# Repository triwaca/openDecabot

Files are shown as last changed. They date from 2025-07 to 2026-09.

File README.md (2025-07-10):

# openDecabot
The easiest 3D printed robot you can assemble and program using Wemos D1 Mini Shields and Arduino IDE, powered by ESP8266. 

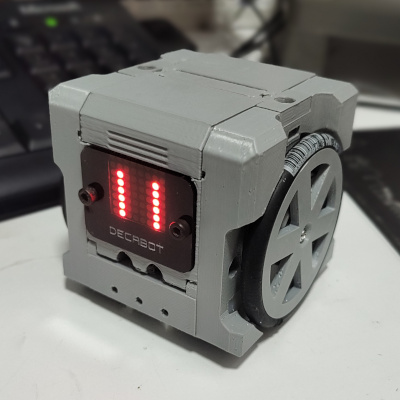
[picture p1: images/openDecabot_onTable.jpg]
Decabot robot on a Table

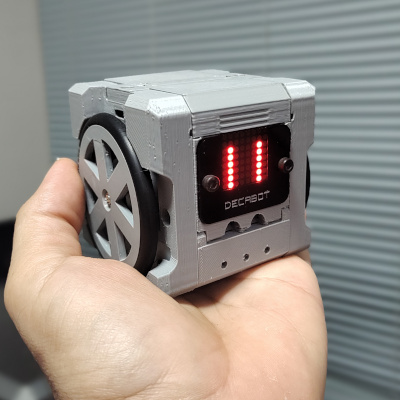
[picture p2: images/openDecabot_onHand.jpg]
A hand holding a Decabot robot


## Hardware
### ESP8266 microcontroler
Open Decabot® uses the ESP8266 controler, in the Wemos Mini form factor, wich allows to use small shields to expand its capacities. In the simplest version, this robot uses a LED matrix shield and a custom connection shield, besides the Wemos D1 mini. The custom shield can be build with a PCB perfboard, a few pin header connections, and some soldering skills. 

By using the Espressif ESP8266 platform, the open Decabot® is nativelly equiped with Wi-Fi capabilities, allowing great IoT experiences, such as remote control and telemetry. 

More information about Wemos platform and a list of main shields available can be found on www.wemos.cc .

### Servo Motors
The open Decabot® robot uses two 360 servo motors to drive its wheels. It's the simplest solution for small robots, since the servo motors didin't require H bridge circuits (they already have those inside!) and can be connected directly to the ESP8266 pins. 

### 3D printed body
You can assemble your Open Decabot® using 3D printed parts. The basic chassis uses only 8 3D printed pieces, and can be assembled using a few screws. The 3D files can be found on **3dPrint** folder. 

### Simple AA batteries for power
Under the open Decabot® you can find a 4 x AA battery support, who can supply up to 6V directly to ESP board. This option simplifies the hardware, since the Wemos Mini board can hold the maxminum 6 volts, lowering the tension to 3 volts. Users can hack the project to use LiIon batteries, combined with the Wemos LiPo Battery Shield (https://www.wemos.cc/en/latest/d1_mini_shield/battery.html) for charging and step up the voltage to 5 volts. 

### Easy access to USB ports
There are two ports on the upper part of the robot who can be used to access the USB port (for firmware/Arduino sketch update), and other wiring and shield needs. 

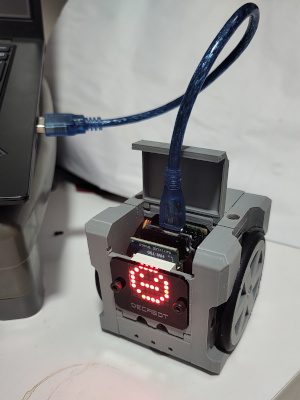
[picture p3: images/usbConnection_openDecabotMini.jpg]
Decabot robot conneceted using USB cable to a computer


### Bill of Materials - BOM
- 1 x Wemos D1 Mini ESP8266 controller
- 2 x Servo 5V 360
- 1 x Wemos LED Matrix Shield
- 1 x custom PCB board (check wiki how to build one) or 1 x Decabot Mini Shield PCB (see **/decabotMiniShield** folder)
- 1 x battery support for 4 x AA
- 1 x acrylic frontface + 2 hallen 3mm screws (optional)
- 7 x screws 3mm, 12mm long
- 2 x rubber o-ring for wheels, size 2" or 50mm (ref: DN50)
- 4 x AA batteries

### Decabot Mini Shield

#### Homemade PDB
Wemos platform does not have a simple shield board to connect servos, so you need a homemade board to use. It's goal is just to simplify the connection between the controller and the motors. A homemade PDB board can be assembled just to connect the main components to the Wemos board: Battery to 5V pin, and servos to D0 and D6 pins, as shown below:

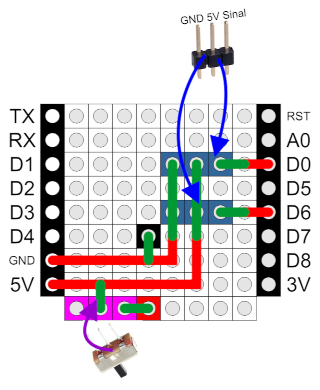
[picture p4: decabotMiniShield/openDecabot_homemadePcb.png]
Homemade Decabot Mini PCB


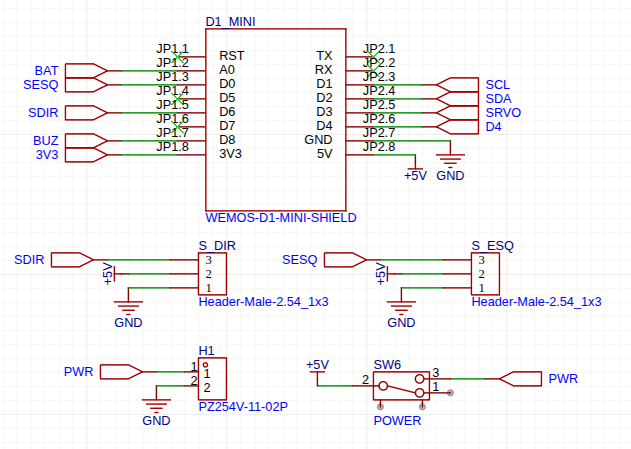
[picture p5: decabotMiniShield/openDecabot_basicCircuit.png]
Homemade PCB circuit


#### Buy the Decabot Shield

Help funding this project by buying our dedicated shield. It is the easiest way to enjoy all the possibilities of your Open Decabot Robot!

- Easy access to Servo connections
- On-off switch
- Included buzzer for sounds
- Easy connection for extra sensors, such as line-folowing sensors
- Dedicated connection to Gyroscope/Accelerometer, for mapping projects
- Dedicated connection to I2C modules, such as OLED displays, distance sensors, RGB sensors and RFID/NFC sensors

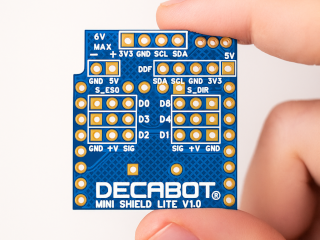
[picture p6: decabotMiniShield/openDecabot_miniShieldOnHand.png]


More information about commercial partnership on WIKI soon.

## Arduino Codes

The Arduino sketches can be found on **/ArduinoSketch** folder. You can simply copy this folder inside your Arduino folder on your computer, and open the `.ino` files. 

Remember that Decabot platform is based on `ESP8266` chip, in Wemos D1 Mini form factor. Your Arduino IDE must be proper set to manage ESP8266 family. To se if it is ready, go to `Tools` menu, then `Boards`, and look for `ESP8266 boards`. You must find `Wemos D1 Mini` there. If not, google for _installing ESP8266 on Arduino IDE_.

Some sketches uses libraries who must be installed before. See instructions on each sketch how to proceed. 

## 3D project source
The 3D source project was all designed on Tinkercad (yes!), and can be forked using the link below:
https://www.tinkercad.com/things/dYy4XWihfYu-opendecabot-mini-v10

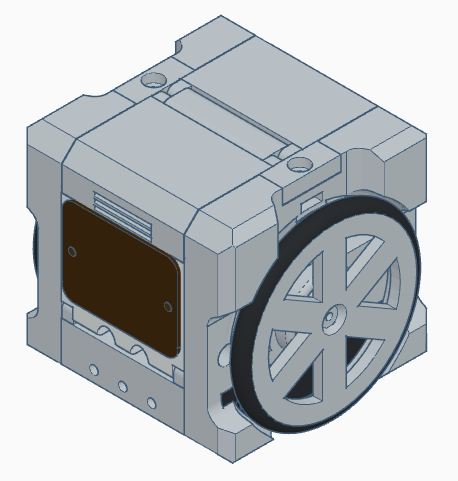
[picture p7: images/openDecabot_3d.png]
Decabot robot on Tinkercad


## Decabot® Trade Mark
Besides this project is open source, the Decabot® name is a registered trademark from Decano Kits Company, and should not be used without proper consent. 

## Open Source Licenses

Open Decabot® project is licensed under CC BY-NC-SA 4.0. You are free to:

- Share — copy and redistribute the material in any medium or format
- Adapt — remix, transform, and build upon the material

Under the following terms:

- Attribution — You must give appropriate credit , provide a link to the license, and indicate if changes were made . You may do so in any reasonable manner, but not in any way that suggests the licensor endorses you or your use.
- NonCommercial — You may not use the material for commercial purposes .
- ShareAlike — If you remix, transform, or build upon the material, you must distribute your contributions under the same license as the original.

https://creativecommons.org/licenses/by-nc-sa/4.0/

Creative Commons License By NC SA

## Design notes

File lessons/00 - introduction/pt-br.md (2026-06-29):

# Introdução: Plataforma Wemos D1 Mini

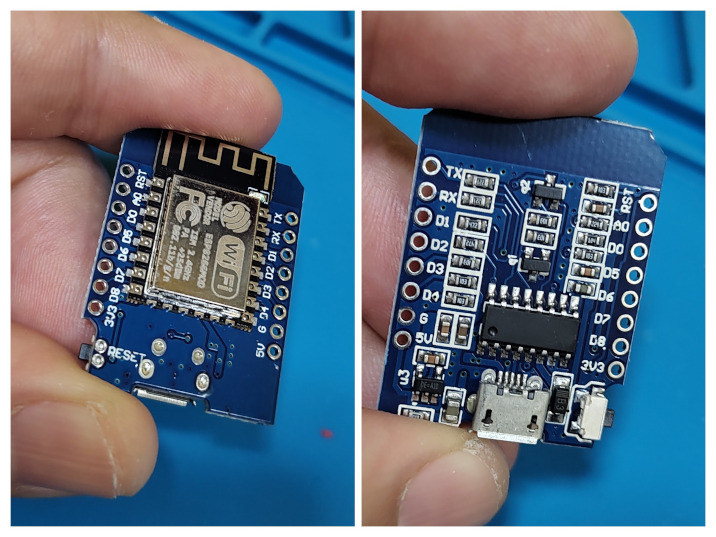
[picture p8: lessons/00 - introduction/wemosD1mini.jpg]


A plataforma **Wemos D1 Mini** é uma das placas de desenvolvimento mais populares e eficientes do ecossistema de Internet das Coisas (IoT) e sistemas embarcados. Baseada no módulo Wi-Fi **ESP8266EX**, ela combina um tamanho extremamente reduzido (form factor *mini*) com um poder de processamento e conectividade robustos, tornando-se uma ferramenta indispensável tanto para o ensino acadêmico quanto para o desenvolvimento de protótipos avançados de robótica open-source e automação.

## 1. Características Técnicas

O Wemos D1 Mini supera as placas tradicionais de 8 bits (como o Arduino Uno) em quase todas as métricas de desempenho, operando com uma arquitetura de 32 bits e conectividade sem fio nativa.

* **Microcontrolador:** ESP-8266EX (Processador RISC de 32 bits Tensilica L106)
* **Tensão de Operação:** 3.3V (Atenção: as entradas não são tolerantes a 5V de forma direta)
* **Tensão de Entrada (USB/Pino 5V):** 4.75V a 10V (possui regulador interno para 3.3V)
* **Velocidade de Clock:** 80 MHz (podendo ser configurado até 160 MHz)
* **Memória Flash:** 4 Megabytes (32 Megabits) para armazenamento de código e sistema de arquivos (SPIFFS/LittleFS)
* **SRAM:** Cerca de 50 KB disponíveis para o usuário
* **Conectividade:** Wi-Fi integrado 802.11 b/g/n com antena embutida na PCB
* **Pinos de Entrada/Saída Digital (GPIO):** 11 pinos, todos com suporte a Interrupção, PWM, I2C e One-Wire (exceto o pino D0)
* **Pino de Entrada Analógica (ADC):** 1 entrada (A0) com resolução de 10 bits (tensão máxima de entrada de 3.2V devido ao divisor resistivo interno da placa; o chip puramente aceita até 1V)
* **Interface USB:** Conversor USB-Serial integrado (geralmente CH340 ou CP2104) com conector Micro-USB

---

## 2. Pinagem (Pinout) e Funções Especiais

Ao montar sua Wemos D1 mini lembre-se de escolher corretamente o pino duplo, posicionando para cima os pinos fêmeas, e na parte de baixo os pinos machos, conforme imagem:

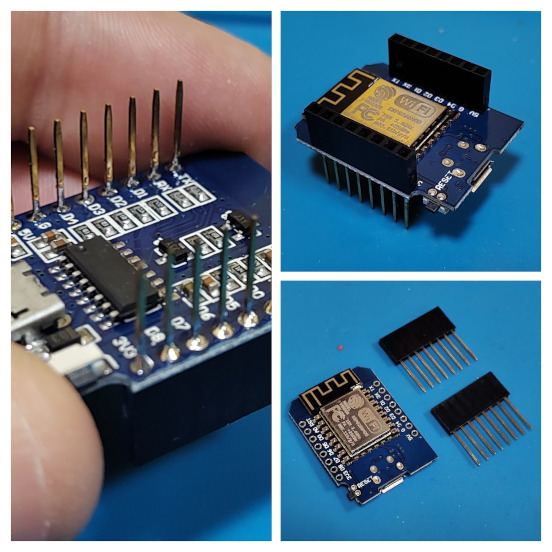
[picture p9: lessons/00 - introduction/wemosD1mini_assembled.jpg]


Compreender a pinagem do Wemos D1 Mini é fundamental, pois os rótulos gravados na placa (D0 a D8) não correspondem diretamente aos números das portas lógicas (GPIO) internos usados na programação.
| Rótulo na Placa | GPIO Interno | Funções Principais / Notas de Boot |
| :--- | :--- | :--- |
| **TX** | GPIO 1 | Transmissão Serial (U0TXD). Pisca no boot. |
| **RX** | GPIO 3 | Recepção Serial (U0RXD). Alto no boot. |
| **D0** | GPIO 16 | Wake do modo Deep Sleep. Sem suporte a PWM/Interrupção. |
| **D1** | GPIO 5 | **SCL** (I2C por hardware / padrão). |
| **D2** | GPIO 4 | **SDA** (I2C por hardware / padrão). |
| **D3** | GPIO 0 | Conectado a um resistor de Pull-up interno. **Deve estar em nível ALTO no boot** para entrar no modo de execução. |
| **D4** | GPIO 2 | Conectado ao **LED Azul Integrado** (lógica invertida: LOW liga, HIGH desliga). Emite dados de debug no boot. |
| **D5** | GPIO 14 | **CLK** (SPI por hardware). |
| **D6** | GPIO 12 | **MISO** (SPI por hardware). |
| **D7** | GPIO 13 | **MOSI** (SPI por hardware). |
| **D8** | GPIO 15 | **CS** (SPI por hardware). Conectado a um resistor de Pull-down interno. **Deve estar em nível BAIXO no boot**. |
| **A0** | ADC0 | Entrada Analógica (0V a 3.2V). |
| **RST** | RST | Pino de Reset da placa (Ativo em nível BAIXO). |
| **5V** | — | Saída de 5V (quando alimentado por USB) ou Entrada de Alimentação Externa. |
| **3V3** | — | Saída do regulador interno de 3.3V (máximo ~500mA). |
| **GND** | — | Referência de aterramento (Ground). |

---

## 3. Vantagens do Uso de Shields Wemos D1 Mini

Uma das maiores forças desta plataforma é o seu ecossistema de **Shields** (placas de expansão modulares). Elas eliminam a necessidade de fiação complexa e trazem vantagens significativas:

* **Prototipagem Rápida e Limpa:** As shields possuem exatamente o mesmo tamanho e disposição de pinos da placa principal. Elas podem ser empilhadas diretamente usando barras de pinos macho-fêmea, eliminando emaranhados de cabos jumpers e o uso excessivo de protoboards.
* **Redução de Pontos de Falha:** Mau contato em fios jumpers é um dos problemas mais comuns em projetos laboratoriais e robóticos móveis. A conexão soldada das shields garante integridade mecânica e elétrica.
* **Compactação do Projeto:** Permite criar dispositivos IoT completos (com sensores, displays e atuadores) que cabem dentro de pequenas caixas ou estruturas robóticas compactas.
* **Variedade de Recursos Prontos:** Existem dezenas de shields oficiais e compatíveis no mercado, tais como:
  * *Relay Shield:* Para controle de cargas de alta tensão (lâmpadas, motores).
  * *OLED Shield:* Telas compactas de 64x48 ou 128x64 pixels para interface visual.
  * *DHT11/DHT22 Shield:* Sensores de temperatura e umidade prontos para leitura.
  * *Battery Shield:* Circuito integrado para carregar e gerenciar baterias de Lítio (LiPo) de 3.7V, ideal para robôs móveis.
  * *MicroSD Card Shield:* Para datalogging (registro de dados locais).

Conheça todas as shield disponíveis acessando o site wemos em www.wemos.cc .

---

## 4. Tutorial: Configurando a Arduino IDE para o Wemos D1 Mini

Para programar o Wemos D1 Mini usando a linguagem baseada em C/C++ do Arduino, siga os passos abaixo:

### Passo 1: Adicionar a URL do ESP8266 nas Preferências

1. Abra a **Arduino IDE**.

2. No menu superior, clique em **Arquivo** > **Preferências** (no macOS: *Arduino IDE* > *Settings*).

3. Localize o campo chamado **URLs Adicionais para Gerenciadores de Placas**.

4. Cole a seguinte URL exatamente como descrita:
   
   ```text
   http://arduino.esp8266.com/stable/package_esp8266com_index.json
   ```

5. Clique em **OK** para salvar.
   
   ### Passo 2: Instalar o Pacote de Placas ESP8266

6. No menu lateral esquerdo da Arduino IDE, clique no ícone do **Gerenciador de Placas** (ou vá em *Ferramentas* > *Placa* > *Gerenciador de Placas...*).

7. Na barra de pesquisa que aparecer, digite **esp8266**.

8. Localize o pacote chamado **esp8266** criado pela *ESP8266 Community*.

9. Clique no botão **Instalar** e aguarde o término do download e configuração (isso pode levar alguns minutos).
   
   ### Passo 3: Selecionar a Placa Correta

10. Vá no menu superior em **Ferramentas** > **Placa** > **ESP8266 Boards**.

11. Procure e selecione a opção **LOLIN(WEMOS) D1 R2 & mini**.
    
    ### Passo 4: Instalar os Drivers e Conectar a Placa

12. Conecte o Wemos D1 Mini ao computador através de um cabo Micro-USB (certifique-se de que o cabo suporta transferência de dados, e não apenas energia).

13. Se a sua placa utilizar o chip de comunicação **CH340** e o seu sistema operacional não o reconhecer automaticamente, faça o download e a instalação do driver *CH340 Serials Driver* (disponível para Windows, Mac e Linux).

14. Na Arduino IDE, vá em **Ferramentas** > **Porta** e selecione a porta correspondente (ex: `COM3`, `COM4` no Windows, ou `/dev/tty.usbserial` no Unix).
    
    ### Passo 5: Teste Prático (Blink)
    
    Para validar se tudo está funcionando, carregue o código de teste padrão que pisca o LED embutido utilizando a constante correta da placa:
    
    ```cpp
    void setup() {
        // Configura o pino do LED interno como saída
        pinMode(LED_BUILTIN, OUTPUT); 
    }
    void loop() {
        // Liga o LED (Lógica invertida: LOW ativa o LED interno no Wemos)
        digitalWrite(LED_BUILTIN, LOW); 
        delay(5000); // Mantém ligado por 5 segundos
    
        // Desliga o LED
        digitalWrite(LED_BUILTIN, HIGH); 
    delay(1000); // Mantém desligado por 1 segundo
    }
    ```

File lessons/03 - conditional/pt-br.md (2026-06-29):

# Condicionais e Comunicação Serial no Wemos D1 Mini

Este repositório contém um guia prático projetado para introduzir estudantes de robótica, automação e sistemas embarcados aos conceitos de **Comunicação Serial** e **Estruturas Condicionais (`if`, `else if`, `else`)** utilizando a placa **Wemos D1 Mini (ESP8266)** e a plataforma Arduino.

## 📋 Pré-requisitos

Antes de iniciar, certifique-se de ter os seguintes itens configurados:

### Hardware

* 1x Placa Wemos D1 Mini (ou qualquer módulo baseado no ESP8266)

* 1x Cabo de dados Micro-USB
  
  ### Software

* **Arduino IDE** (versão 1.8.x ou 2.x)

* Placas da família **ESP8266 instaladas** na IDE (Gerenciador de Placas)

* Drivers do chip de comunicação USB instalados (geralmente CH340)

---

## ⚡ Passo 1: O que é a Comunicação Serial?

A **Comunicação Serial** funciona como uma ponte de texto entre o microcontrolador e o seu computador. Em projetos de desenvolvimento, ela é a nossa principal ferramenta de diagnóstico (debug), permitindo-nos "espiar" o que está acontecendo dentro do chip.
No ecossistema Arduino, iniciamos essa comunicação usando o comando:

```cpp
Serial.begin(velocidade);
```

> [!IMPORTANT]
> **Por que usar 115200 bps no Wemos D1 Mini?**
> Diferente do Arduino Uno clássico (que costuma usar 9600), os microcontroladores da família ESP8266 inicializam o bootloader a uma taxa de **115200 bps**. Configurar o sistema nessa velocidade evita que você veja caracteres corrompidos ou ilegíveis (lixo de memória) na tela no momento em que a placa é resetada ou ligada.

### Comandos de Escrita Serial:

* `Serial.print("Texto");` -> Envia a informação e mantém o cursor na **mesma linha**.
* `Serial.println("Texto");` -> Envia a informação e **pula para a próxima linha** (adiciona uma quebra de linha `\n` ao final).

---

## 🔍 Passo 2: Como Visualizar os Dados na Arduino IDE

Para conseguir ler o que o Wemos D1 Mini está enviando, siga o procedimento abaixo:

1. Conecte o Wemos D1 Mini ao computador pelo cabo USB.
2. Na Arduino IDE, vá em **Ferramentas > Placa** e selecione `LOLIN(WEMOS) D1 R2 & mini` (ou `Generic ESP8266 Module`).
3. Vá em **Ferramentas > Porta** e selecione a porta COM associada à sua placa.
4. Clique no ícone do **Monitor Serial** (uma lupa no canto superior direito da IDE) ou pressione o atalho `Ctrl + Shift + M`.
5. **Ajuste essencial:** Na janela do Monitor Serial que se abriu, mude a velocidade no menu suspenso para **115200 baud**. Se estiver em outra velocidade, você não conseguirá ler o texto correto.

---

## 🧠 Passo 3: Entendendo as Estruturas Condicionais

As condicionais permitem que o microcontrolador execute ações diferentes dependendo do estado das variáveis ou sensores.

* **`if` (Se):** Avalia se uma condição é verdadeira. Se for, executa o bloco de código interno.
* **`else if` (Senão se):** Fornece uma nova condição para ser testada caso as anteriores tenham sido falsas.
* **`else` (Senão):** É a zona de escape. Executa um código padrão caso **nenhuma** das condições anteriores tenha sido atendida.

---

## 💻 Passo 4: Código Prático (Simulação de um Sensor de Distância)

Neste exemplo realístico, simulamos a lógica interna de um pequeno robô móvel que precisa desviar de obstáculos. A variável `distanciaObstaculo` decresce a cada ciclo para forçar o código a passar por todas as ramificações lógicas.
Copie o código abaixo, cole na sua Arduino IDE e clique em **Carregar (Upload)**:

```cpp
/**
 * @file Tutorial_Condicionais.ino
 * @brief Aprendendo condicionais e comunicação serial com o Wemos D1 Mini.
 * @author Professor / Instrutor
 */
// Variável global para simular a leitura de distância em centímetros (cm)
int distanciaObstaculo = 35; 
void setup() {
  // Inicializa a comunicação serial a 115200 bits por segundo (bps)
  Serial.begin(115200);

  // Pequeno intervalo de segurança para inicialização estável da placa
  delay(1000); 

  Serial.println("");
  Serial.println("=========================================");
  Serial.println("   SISTEMA DE DECISÃO LOGICA DO ROBÔ     ");
  Serial.println("=========================================");
}
void loop() {
  // Exibe a distância simulada atual no monitor
  Serial.print("Sensor de Distância: ");
  Serial.print(distanciaObstaculo);
  Serial.println(" cm");
  // --- INÍCIO DA TOMADA DE DECISÃO ---

  // Condição 1: Perigo imediato
  if (distanciaObstaculo <= 10) {
    Serial.println(" Alerta: [PERIGO] - Parar imediatamente! Risco de colisão.");
  }

  // Condição 2: Zona de atenção (Uso do operador lógico '&&' para verificar o intervalo)
  else if (distanciaObstaculo > 10 && distanciaObstaculo <= 30) {
    Serial.println(" Alerta: [ATENÇÃO] - Reduzir velocidade. Obstáculo próximo.");
  }

  // Condição 3: Caminho livre (Qualquer valor acima de 30)
  else {
    Serial.println(" Status: [LIVRE] - Velocidade máxima permitida.");
  }
  Serial.println("-----------------------------------------");
  // --- SIMULAÇÃO DA MUDANÇA DE ESTADO ---
  // Subtrai 8 cm da distância a cada execução para simular a aproximação do robô
  distanciaObstaculo = distanciaObstaculo - 8;
  // Se a distância se tornar negativa, reiniciamos a simulação para fins didáticos
  if (distanciaObstaculo < 0) {
    distanciaObstaculo = 40; 
    Serial.println("\n>>> [RESET] Reiniciando simulação de trajetória... <<<\n");
  }
  // Tempo de espera de 3 segundos para que os alunos possam ler confortavelmente
  delay(3000); 
}
```

---

## 📈 Resultado Esperado no Monitor Serial

Ao abrir o Monitor Serial configurado corretamente em `115200 baud`, os alunos deverão observar a seguinte sequência cíclica de mensagens de texto na tela:

```text
=========================================
   SISTEMA DE DECISÃO LOGICA DO ROBÔ     
=========================================
Sensor de Distância: 35 cm
 Status: [LIVRE] - Velocidade máxima permitida.
-----------------------------------------
Sensor de Distância: 27 cm
 Alerta: [ATENÇÃO] - Reduzir velocidade. Obstáculo próximo.
-----------------------------------------
Sensor de Distância: 19 cm
 Alerta: [ATENÇÃO] - Reduzir velocidade. Obstáculo próximo.
-----------------------------------------
Sensor de Distância: 11 cm
 Alerta: [ATENÇÃO] - Reduzir velocidade. Obstáculo próximo.
-----------------------------------------
Sensor de Distância: 3 cm
 Alerta: [PERIGO] - Parar imediatamente! Risco de colisão.
-----------------------------------------
>>> [RESET] Reiniciando simulação de trajetória... <<<
Sensor de Distância: 40 cm
 Status: [LIVRE] - Velocidade máxima permitida.
```

---

## 🚀 Desafios para Fixação (Prática em Laboratório)

Para garantir o aprendizado e testar o raciocínio lógico dos estudantes, proponha as seguintes modificações no código:

1. **Alerta Intermediário Exato:** Peça aos alunos para adicionarem uma condição usando `else if` que identifique quando a distância for exatamente `15` cm e imprima uma instrução específica no terminal, por exemplo: `" Status: [INFO] - Manobrar para a direita."` (Lembre-os de usar o operador de igualdade `==`).
2. **Alteração do Passo de Atualização:** Peça para alterarem o decremento do sensor (atualmente em `- 8`) para um valor menor, como `- 3`, e incentive-os a analisar o impacto desse valor na frequência com que os alertas mudam de estado.
3. **Uso de Operadores Relacionais:** Peça para modificarem o código para que o status `[PERIGO]` passe a cobrir qualquer valor menor ou igual a `15` cm, ajustando os intervalos lógicos subsequentes de forma coerente.

---

## 🛠️ Resolução de Problemas Comuns

* **O Monitor Serial exibe caracteres estranhos (`⸮⸮⸮` ou interrogações):** A velocidade do monitor está diferente de `115200`. Altere a caixa de seleção no canto inferior direito para o valor correto.
* **Erro ao carregar o código (Failed to connect to ESP8266):** O cabo USB pode ser apenas de carregamento (sem linhas de dados), a porta COM errada foi selecionada ou os drivers do chip CH340 precisam ser reinstalados.

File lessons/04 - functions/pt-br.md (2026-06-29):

# Tutorial Prático: Criando e Utilizando Funções no Arduino

Bem-vindos a este guia pedagógico sobre estruturação de código. Quando nossos programas começam a crescer — seja controlando um semáforo complexo, lendo múltiplos sensores ou gerenciando a movimentação de um robô como o Decabot —, colocar todo o código dentro das funções `setup()` e `loop()` torna o projeto confuso, difícil de depurar e propenso a erros.
As **funções** são blocos de código independentes e reutilizáveis que realizam tarefas específicas. Elas nos ajudam a modularizar o sistema, evitar a repetição de código (princípio DRY - *Don't Repeat Yourself*) e tornar a leitura muito mais intuitiva.

---

## A Estrutura de uma Função

Toda função em C/C++ (linguagem base do Arduino) segue uma anatomia padrão:

```cpp
tipoDeRetorno nomeDaFuncao(tipoParametro1 parametro1, tipoParametro2 parametro2) {
    // Corpo da função (código que será executado)
    return valor; // Opcional (apenas se houver tipo de retorno)
}
```

Para entender como utilizá-las na prática, vamos dividi-las em 4 categorias baseadas na presença de **parâmetros de entrada** (dados que a função recebe) e **retornos** (dados que a função envia de volta).

## 1. Funções Sem Parâmetros e Sem Retorno

É o tipo mais simples de função. Ela serve apenas para agrupar um conjunto de instruções que você deseja executar repetidamente, sem a necessidade de enviar ou receber dados de fora.

* **Tipo de retorno:** Usamos a palavra-chave `void` (vazio), indicando que ela não devolve nada.

* **Parâmetros:** Os parênteses ficam vazios `()`.
  
  ### Exemplo Prático:
  
  Imagine que queremos criar um padrão de alerta visual piscando um LED de forma específica.
  
  ```cpp
  const int ledPin = D4; // LED embutido no Wemos D1 Mini
  
  void setup() {
      pinMode(ledPin, OUTPUT);
  }
  
  void loop() {
      // Chamamos a nossa função personalizada
      emitirAlertaSOS(); 
      
      delay(3000); // Aguarda 3 segundos antes de repetir o Alerta
  }
  
  // Definição da nossa função
  void emitirAlertaSOS() {
      // Três piscadas rápidas
      for(int i = 0; i < 3; i++) {
        digitalWrite(ledPin, LOW);  // Liga (Active-LOW no Wemos)
        delay(200);
        digitalWrite(ledPin, HIGH); // Desliga
        delay(200);
      }
  }
  ```

---

## 2. Funções Com Parâmetros e Sem Retorno

Muitas vezes, queremos que a função execute a mesma tarefa, mas com dados dinâmicos. Os parâmetros de entrada funcionam como variáveis locais que recebem valores no momento em que a função é chamada.

* **Tipo de retorno:** Continua sendo `void`.

* **Parâmetros:** Especificamos o tipo e o nome de cada variável dentro dos parênteses.
  
  ### Exemplo Prático:
  
  Em vez de piscar sempre no mesmo ritmo estático, vamos passar o número de piscadas e o tempo de duração por parâmetro.
  
  ```cpp
  const int ledPin = D4;
  
  void setup() {
      pinMode(ledPin, OUTPUT);
  }
  
  void loop() {
      // Pisca o LED 5 vezes com intervalo de 100ms (Rápido)
      piscarLed(5, 100);
      delay(2000);
      
      // Pisca o LED 2 vezes com intervalo de 1000ms (Lento)
      piscarLed(2, 1000);
      delay(2000);
  }
  
  // Função que aceita dois parâmetros inteiros
  void piscarLed(int quantidade, int tempoEspera) {
      for(int i = 0; i < quantidade; i++) {
        digitalWrite(ledPin, LOW);
        delay(tempoEspera);
        digitalWrite(ledPin, HIGH);
        delay(tempoEspera);
      }
  }
  ```

---

## 3. Funções Sem Parâmetros e Com Retorno

Essas funções realizam um processamento interno (como ler um sensor ou calcular uma constante fixa) e enviam o resultado de volta para o bloco de código que a chamou.

* **Tipo de retorno:** Substituímos o `void` pelo tipo de dado que será devolvido (ex: `int`, `float`, `char`, `bool`).

* **Corpo da função:** É obrigatório o uso da palavra-chave `return` seguida do valor ou variável.
  
  ### Exemplo Prático:
  
  Simulação da leitura de um sensor analógico (como um LDR de luminosidade conectado ao pino A0) que converte a leitura diretamente em uma escala percentual.
  
  ```cpp
  void setup() {
      Serial.begin(9600);
  }
  
  void loop() {
      // A variável 'luminosidade' recebe o valor devolvido pela função
      int luminosidade = lerLuminosidadePercentual();
      
      Serial.print("Luminosidade atual: ");
      Serial.print(luminosidade);
      Serial.println("%");
      
      delay(1000);
  }
  
  // Função que retorna um número inteiro
  int lerLuminosidadePercentual() {
      int leituraBruta = analogRead(A0); // Lê um valor entre 0 e 1024
      
      // Mapeia o valor bruto para uma escala de 0 a 100
      int percentual = map(leituraBruta, 0, 1023, 0, 100); 
      
      return percentual; // Envia o dado processado de volta
  }
  ```

---

## 4. Funções Com Parâmetros e Com Retorno

Este é o nível mais completo e poderoso de uma função. Ela recebe um ou mais dados de entrada, realiza operações matemáticas ou lógicas complexas e devolve um resultado limpo. Elas funcionam exatamente como as funções matemáticas clássicas: $f(x, y) = resultado$.

### Exemplo Prático:

Uma função utilitária para converter uma temperatura de Celsius (comum no Brasil) para Fahrenheit.

```cpp
void setup() {
  Serial.begin(9600);
}
void loop() {
  float tempCelsius = 25.5;

  // Passamos o valor float e guardamos o retorno float
  float tempFahrenheit = converterCelsiusParaFahrenheit(tempCelsius);

  Serial.print(tempCelsius);
  Serial.print(" C equivale a ");
  Serial.print(tempFahrenheit);
  Serial.println(" F");

  delay(5000);
}

// Recebe um float e retorna um float
float converterCelsiusParaFahrenheit(float celsius) {
  float fahrenheit = (celsius * 9.0 / 5.0) + 32.0;
  return fahrenheit;
}
```

---

## Boas Práticas ao Criar Funções

1. **Nomes descritivos:** Use verbos no infinitivo ou termos que deixem claro o que a função faz (ex: `calcularMedia()`, `acionarMotores()`, e não nomes vagos como `funcao1()`, `processo()`).
2. **Responsabilidade Única:** Uma função deve fazer apenas **uma** coisa bem feita. Se uma função chamada `lerBotao()` também acende um LED e envia dados via Wi-Fi, divida-a em três funções separadas.
3. **Escopo de Variáveis:** Variáveis criadas dentro de uma função existem apenas dentro dela (variáveis locais). Elas são destruídas assim que a função termina a execução.

---

## 🚀 Desafio Prático para os Alunos

Para consolidar o conhecimento desta aula de laboratório, modifique o circuito do Semáforo Simples ou utilize a sua protoboard para resolver o seguinte problema de automação:

### O Sistema de Resfriamento Inteligente

Você deve criar um programa que monitore a temperatura de uma máquina de laboratório e acione um LED de alerta (simulando um cooler ou alarme de segurança).

1. Escreva uma função com retorno chamada `obterTemperatura()` que simule ou leia um sensor de temperatura e retorne o valor em graus Celsius (`float`).
2. Escreva uma função chamada `controlarAlerta()` que receba a temperatura por parâmetro (`float`), não retorne nada (`void`), e execute a seguinte lógica:
   * Se a temperatura for **menor que 30.0°C**, o LED deve ficar **desligado**.
   * Se a temperatura estiver **entre 30.0°C e 40.0°C**, o LED deve piscar **lentamente** (intervalo de 1 segundo).
   * Se a temperatura for **maior que 40.0°C**, o LED deve piscar **rapidamente** (intervalo de 200ms), indicando estado crítico de superaquecimento.
3. No seu `loop()`, faça a chamada ordenada dessas duas funções estruturadas de forma limpa.

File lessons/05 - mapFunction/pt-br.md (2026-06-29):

# Tutorial Prático: Função `map()` e Leitura Analógica no Wemos D1 Mini

Este repositório contém um guia prático para ensinar como utilizar a função `map()` da Arduino IDE. Você aprenderá a ler um sensor analógico (potenciômetro) e converter seus dados brutos para diferentes escalas úteis (porcentagem, graus e escala invertida).

## 📋 Pré-requisitos

### Hardware

* 1x Placa Wemos D1 Mini (ESP8266)

* 1x Potenciômetro (ex: 10kΩ)

* 1x Protoboard

* 3x Jumpers (fios macho-macho)

* 1x Cabo Micro-USB de dados
  
  ### Software

* Arduino IDE instalada e configurada para placas ESP8266.

---

## 📖 Passo 1: A Teoria – O que é a função `map()`?

Na programação com Arduino, muitas vezes lemos um valor que está em uma **escala A** e precisamos convertê-lo proporcionalmente para uma **escala B**. A função `map()` faz essa "regra de três" automaticamente.
A sintaxe exige 5 parâmetros:

```cpp
resultado = map(valor_lido, de_min, de_max, para_min, para_max);
```

* **`valor_lido`**: Variável com o número original.

* **`de_min` e `de_max`**: Intervalo original (ex: o que o sensor gera).

* **`para_min` e `para_max`**: Intervalo de destino (ex: para onde você quer converter).
  **Exemplo prático:** O conversor analógico-digital (ADC) do Wemos D1 Mini lê tensões no pino `A0` e transforma em números de **0 a 1023**. Para converter essa leitura em uma porcentagem (de **0 a 100%**):
  
  ```cpp
  porcentagem = map(leitura, 0, 1023, 0, 100);
  ```

---

## 🔌 Passo 2: Montagem do Circuito (Protoboard)

O Wemos D1 Mini possui apenas um pino analógico, o **A0**. Vamos conectar o sinal do nosso potenciômetro nele.

> [!WARNING]
> **Cuidado com a Tensão:** O pino analógico (A0) do Wemos D1 Mini suporta no máximo **3.3V**. Nunca conecte o potenciômetro ao pino de 5V da placa, sob risco de danificar o microcontrolador permanentemente.

### Conexões:

1. Encaixe o potenciômetro na protoboard.
2. **Pino da Esquerda:** Conecte ao pino **3V3** do Wemos.
3. **Pino da Direita:** Conecte ao pino **G** (GND) do Wemos.
4. **Pino Central (Cursor):** Conecte ao pino **A0** do Wemos.
   *(Nota: Inverter as ligações dos pinos das extremidades apenas inverte a direção de leitura, mas não causa danos.)*

---

## 💻 Passo 3: O Código (Prática)

Neste código, vamos ler o valor bruto do potenciômetro (0 a 1023) e convertê-lo para três escalas diferentes.

```cpp
/**
 * @file Tutorial_Map_Potenciometro.ino
 * @brief Prática com função map() e potenciômetro no Wemos D1 Mini.
 */
// Define o pino onde o potenciômetro está conectado
const int pinoPotenciometro = A0; 
void setup() {
  // Inicia a comunicação serial a 115200 bps
  Serial.begin(115200);
  delay(1000); 

  Serial.println("\n--- Iniciando Leitura do Potenciômetro ---");
}
void loop() {
  // 1. Lê o valor bruto do ADC
  // No Wemos D1 Mini, esse valor vai de 0 a 1023
  int valorBruto = analogRead(pinoPotenciometro);
  // 2. Usando a função map() para diferentes aplicações

  // Exemplo A: Convertendo para porcentagem (0 a 100%)
  int porcentagem = map(valorBruto, 0, 1023, 0, 100);
  // Exemplo B: Convertendo para ângulo de um servo motor (0 a 180 graus)
  int anguloServo = map(valorBruto, 0, 1023, 0, 180);
  // Exemplo C: Escala invertida (ex: 10 até 0).
  int contagemRegressiva = map(valorBruto, 0, 1023, 10, 0);
  // 3. Imprimindo os resultados no Monitor Serial
  Serial.print("Bruto: ");
  Serial.print(valorBruto);

  Serial.print(" | Porcentagem: ");
  Serial.print(porcentagem);
  Serial.print("%");
  Serial.print(" | Angulo: ");
  Serial.print(anguloServo);
  Serial.print("°");
  Serial.print(" | Invertido: ");
  Serial.println(contagemRegressiva);
  // Aguarda meio segundo antes de fazer uma nova leitura
  delay(500); 
}
```

---

## 📈 Resultado Esperado no Monitor Serial

Ao abrir o Monitor Serial configurado corretamente em `115200 baud` e girar o potenciômetro, os alunos deverão observar algo parecido com isto:

```text
--- Iniciando Leitura do Potenciômetro ---
Bruto: 0 | Porcentagem: 0% | Angulo: 0° | Invertido: 10
Bruto: 256 | Porcentagem: 25% | Angulo: 45° | Invertido: 7
Bruto: 512 | Porcentagem: 50% | Angulo: 90° | Invertido: 5
Bruto: 1023 | Porcentagem: 100% | Angulo: 180° | Invertido: 0
```

---

## 🚀 Desafio para Fixação (Prática em Laboratório)

Para testar o conhecimento adquirido, tente resolver o seguinte desafio:

> Modifique o código acima para que a função `map()` simule um sensor de temperatura falso. Quando o potenciômetro estiver girado totalmente para a esquerda, o valor exibido deve ser **-20°C**. Quando estiver totalmente para a direita, deve ser **50°C**.
> **Dica:** Lembre-se de alterar os limites de destino (`para_min` e `para_max`) na sua função `map()`.

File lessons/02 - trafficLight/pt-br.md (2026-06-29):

# Semáforo Simples com Wemos D1 Mini

Bem-vindos a mais uma prática do laboratório Lapin. Após aprendermos a piscar o LED interno, vamos expandir nossos conhecimentos para o mundo físico externo utilizando uma protoboard e múltiplos componentes. Neste tutorial, vamos criar um sistema de semáforo clássico.

## 1. Objetivos da Aula

* Entender o funcionamento de múltiplas saídas digitais em sequência.

* Aprender a montar um circuito básico em uma protoboard utilizando componentes externos.

* Programar a lógica de tempo e transição de estados de um semáforo (Verde, Amarelo e Vermelho) na plataforma Wemos D1 Mini (ESP8266).
  
  ## 2. Materiais Necessários

* 1x Placa Wemos D1 Mini (ESP8266)

* 1x Cabo Micro-USB

* 1x Protoboard (Matriz de contatos)

* 3x LEDs de 5mm (1 Vermelho, 1 Amarelo, 1 Verde)

* Fios Jumper (Macho-Macho ou Macho-Fêmea, dependendo de como os pinos da sua placa estão soldados)
  
  > **⚠️ Nota importante sobre Resistores e LEDs:** > O ideal e correto na eletrônica é sempre utilizar resistores (ex: 220Ω ou 330Ω) em série com cada LED. Eles servem para limitar a corrente e evitar que o LED sofra danos. No entanto, para esta prática de laboratório rápida e simples, se você ligar os LEDs diretamente aos pinos digitais do Wemos D1 Mini, eles não irão queimar de imediato. Isso ocorre porque a tensão lógica do ESP8266 é de 3.3V (menor que os típicos 5V do Arduino Uno) e a corrente dos pinos é naturalmente limitada. Apesar disso funcionar para o nosso teste de hoje, lembre-se: em projetos definitivos, como no Decabot, o uso de resistores é indispensável!
  
  ## 3. Montagem do Circuito
1. Conecte a placa Wemos D1 Mini à protoboard, de forma que os pinos estejam acessíveis e que seja possível conectar o cabo USB (veja imagem).
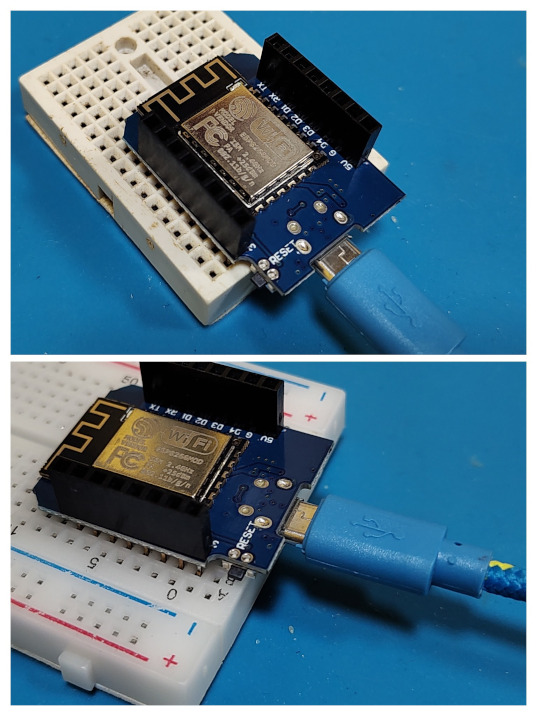
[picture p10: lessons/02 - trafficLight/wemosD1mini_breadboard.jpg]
   

2. Conecte um fio do pino **GND** do Wemos D1 Mini à linha azul (negativa) da protoboard.

3. Insira os 3 LEDs na protoboard. Lembre-se que o pino mais longo do LED é o positivo (Ânodo) e o mais curto, ou o lado com um corte reto na borda de plástico, é o negativo (Cátodo).

4. Conecte os pinos curtos (Cátodos) de todos os LEDs à linha negativa da protoboard.

5. Conecte os pinos longos (Ânodos) aos pinos digitais do Wemos da seguinte forma:
   
   * **LED Vermelho:** Pino **D1**
   
   * **LED Amarelo:** Pino **D2**
   
   * **LED Verde:** Pino **D3**
     
     ## 4. Preparando a Arduino IDE
* Abra a Arduino IDE e certifique-se de que a placa **LOLIN(WEMOS) D1 R2 & mini** está selecionada em **Ferramentas > Placa**.

* Verifique se a porta de comunicação correta (COM no Windows ou /dev/ttyUSB no Mac/Linux) está selecionada em **Ferramentas > Porta**.
  
  ## 5. O Código-Fonte (Sketch)
  
  Copie o código abaixo para a sua IDE. Diferente do nosso primeiro exercício, estes LEDs externos acenderão com nível lógico alto (HIGH).
  
  ```cpp
  /*
  Laboratório Lapin - Prática de Semáforo
  Projeto: Controle de 3 LEDs com Wemos D1 Mini
  */
  // Definição dos pinos
  const int ledVermelho = D1;
  const int ledAmarelo = D2;
  const int ledVerde = D3;
  void setup() {
  // Configura os 3 pinos como saída (OUTPUT)
  pinMode(ledVermelho, OUTPUT);
  pinMode(ledAmarelo, OUTPUT);
  pinMode(ledVerde, OUTPUT);
  }
  void loop() {
  // --- FASE 1: SINAL VERDE ---
  digitalWrite(ledVermelho, LOW);
  digitalWrite(ledAmarelo, LOW);
  digitalWrite(ledVerde, HIGH); // Liga o Verde
  delay(5000); // Mantém por 5 segundos
  
  // --- FASE 2: SINAL AMARELO ---
  digitalWrite(ledVerde, LOW); // Desliga o Verde
  digitalWrite(ledAmarelo, HIGH); // Liga o Amarelo
  delay(2000); // Mantém por 2 segundos
  
  // --- FASE 3: SINAL VERMELHO ---
  digitalWrite(ledAmarelo, LOW); // Desliga o Amarelo
  digitalWrite(ledVermelho, HIGH); // Liga o Vermelho
  delay(5000); // Mantém por 5 segundos
  }
  ```
  
  ## 6. Compilando e Carregando
1. Clique em **Verificar** (ícone do V) para compilar o código e buscar possíveis erros de digitação.

2. Clique em **Carregar** (ícone da seta) para transferir o código para o seu microcontrolador.

3. Aguarde a mensagem "Transferência Concluída". Seu circuito na protoboard já deve estar funcionando, alternando entre Verde, Amarelo e Vermelho no tempo programado!
   
   ## 7. Desafio Prático
   
   Para aprimorar suas habilidades em sistemas embarcados, tente resolver os seguintes problemas alterando o código:

4. **Semáforo de Madrugada:** Crie uma lógica onde, ao invés de ciclar entre as três cores, apenas o LED amarelo pisca continuamente a cada 1 segundo (muito comum nas ruas durante a madrugada).

5. **Semáforo de Pedestres (Avançado):** Adicione mais dois LEDs à protoboard (um Verde e um Vermelho). Programe-os para que o sinal do pedestre só fique Verde enquanto o semáforo dos carros estiver Vermelho.

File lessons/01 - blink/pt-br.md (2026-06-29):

# Piscar um LED (Blink) com o Wemos D1 Mini

Bem-vindos a este guia de introdução prática. Este tutorial foi desenvolvido para capacitar os alunos nas atividades da disciplina de Experimentação Orientada, servindo como base para projetos de robótica open-source, como o *openDecabot*. O objetivo é compreender a estrutura de programação, a pinagem do microcontrolador e a lógica de controle de hardware através da plataforma Wemos D1 Mini, baseada no chip ESP8266.

## 1. Objetivos da Aula

* Configurar o ambiente de desenvolvimento Arduino IDE para o Wemos D1 Mini.
* Compreender o mapeamento de pinos (Pinout) da placa.
* Escrever e carregar um código para controlar o LED embutido (built-in LED).
  
  ## 2. Conhecendo o Hardware: Wemos D1 Mini
  
  O Wemos D1 Mini é uma placa de desenvolvimento compacta com conectividade Wi-Fi nativa, excelente para prototipagem de sistemas embarcados. Um detalhe crucial para iniciantes é o mapeamento dos pinos (GPIO). A numeração impressa na placa (como D1, D2, D4) não corresponde diretamente ao número do GPIO lido internamente pelo chip.
  Neste exercício, utilizaremos o LED azul que já vem soldado na placa. Veja a relação de pinos na tabela abaixo:
  
  | Pino na Placa (Label)                                                                                                                                            | GPIO Interno (ESP8266) | Função e Observações                                                    |
  |:---------------------------------------------------------------------------------------------------------------------------------------------------------------- |:---------------------- |:----------------------------------------------------------------------- |
  | **D4**                                                                                                                                                           | GPIO 2                 | Conectado ao **LED Embutido**. Opera com lógica invertida (Active-LOW). |
  | **Importante:** O LED do Wemos D1 Mini opera em *Active-LOW*. Isso significa que enviar um sinal numérico 0 (LOW) liga o LED, e um sinal 1 (HIGH) desliga o LED. |                        |                                                                         |
  
  ## 3. Materiais Necessários
* 1x Placa Wemos D1 Mini (ESP8266)
* 1x Cabo Micro-USB para transferência de dados
* Computador com a Arduino IDE instalada
  
  ## 4. Preparando a Arduino IDE
1. Abra a Arduino IDE, vá em **Arquivo > Preferências**.

2. No campo de URLs Adicionais para Gerenciadores de Placas, insira o link oficial do pacote ESP8266 e clique em OK.

3. Vá em **Ferramentas > Placa > Gerenciador de Placas...**. Busque por "esp8266" e instale o pacote desenvolvido pela comunidade ESP8266.

4. Após a instalação, vá em **Ferramentas > Placa** e selecione **LOLIN(WEMOS) D1 R2 & mini**.

5. Conecte sua placa ao computador usando o cabo USB e selecione a porta correta em **Ferramentas > Porta**.
   
   ## 5. O Código-Fonte (Sketch)
   
   Copie o código abaixo para a sua IDE. Leia os comentários atentamente para entender o fluxo de execução do programa.
   
   ```cpp
   /*
   Laboratório Lapin - Introdução a Microcontroladores
   Projeto: Blink (Piscar LED) com Wemos D1 Mini
   */
   // O pino D4 (GPIO2) possui o LED azul embutido na placa
   const int ledPin = D4; 
   void setup() {
       // Configura o pino do LED como uma saída (OUTPUT)
       pinMode(ledPin, OUTPUT);
   }
   void loop() {
       // Liga o LED (lembre-se: Active-LOW, então LOW liga o LED)
       digitalWrite(ledPin, LOW);  
   
       // Aguarda 1000 milissegundos (1 segundo)
       delay(1000);                      
   
       // Desliga o LED (HIGH desliga)
       digitalWrite(ledPin, HIGH); 
   
       // Aguarda mais 1 segundo antes de reiniciar o ciclo
       delay(1000);                      
   }
   ```
   
   ## 6. Compilando e Carregando
* Clique no botão **Verificar** (ícone de V) no canto superior esquerdo para compilar o código e verificar se há erros de sintaxe.
* Clique no botão **Carregar** (ícone de Seta para a direita). A IDE irá compilar e transferir o firmware para a memória flash do Wemos D1 Mini.
* Assim que aparecer a mensagem de transferência concluída na parte inferior da tela, o LED azul da sua placa começará a piscar em intervalos de 1 segundo!
  
  ## 7. Desafio Prático
  
  Agora que o código base está funcionando, tente modificar a frequência das piscadas. Experimente fazer o LED piscar rapidamente como um estrobo (exemplo: 100ms ligado, 100ms desligado), ou criar um padrão assimétrico alternando entre tempos longos e curtos na função `delay()`. Esses testes são essenciais para dominar a lógica de tempo em sistemas embarcados antes de avançarmos para o controle de motores e leitura de sensores.

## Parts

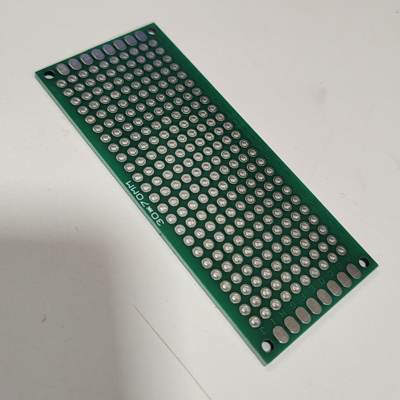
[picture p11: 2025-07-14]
images/componentsWemos_perfBoardNew.JPG

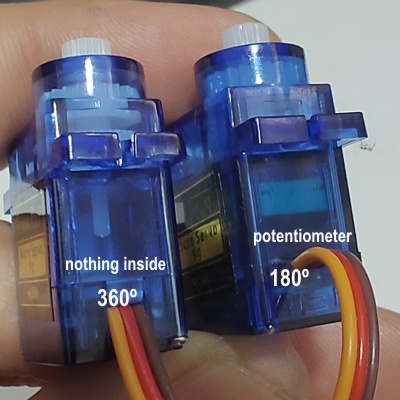
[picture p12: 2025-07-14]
images/componentsWemos_servoDiferences.JPG

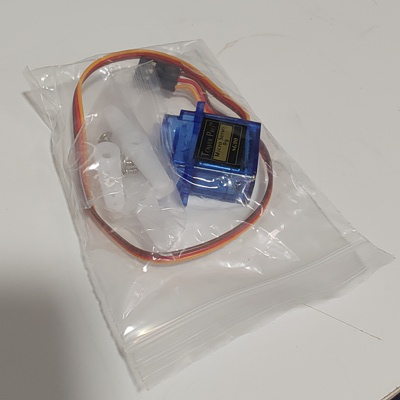
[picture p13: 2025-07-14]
images/componentsWemos_servoPackage.JPG

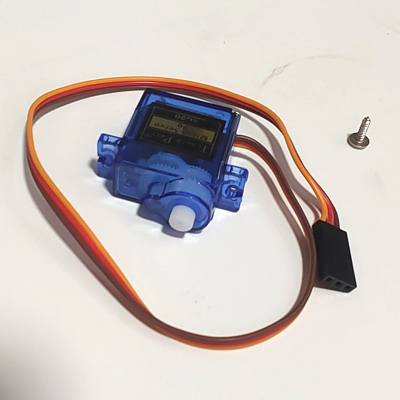
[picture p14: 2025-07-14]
images/componentsWemos_servo.JPG

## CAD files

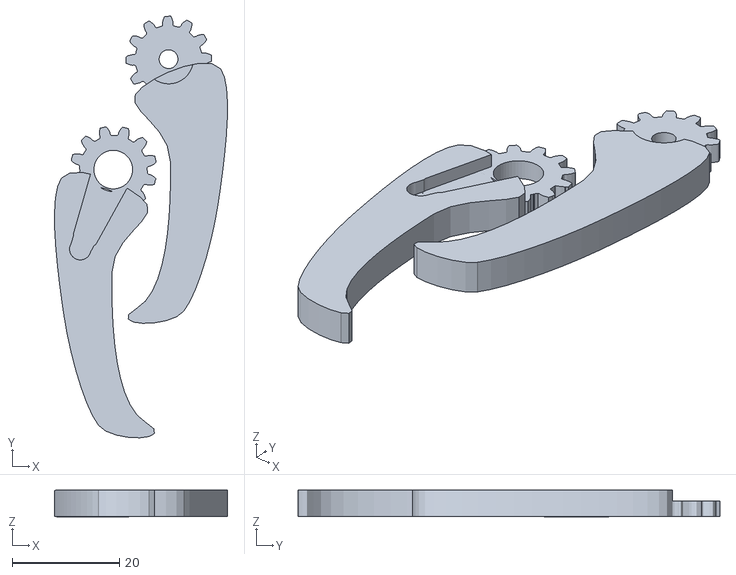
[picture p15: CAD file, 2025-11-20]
3dPrint/accessories/claw_OpenDecabotMINIV1.stl
32.3 x 78.6 x 4.96

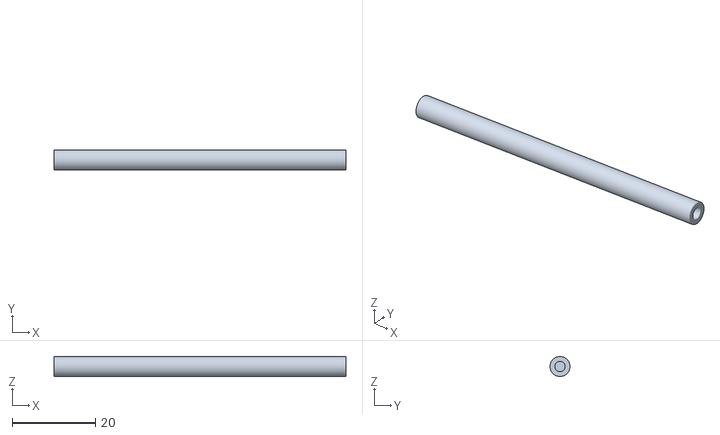
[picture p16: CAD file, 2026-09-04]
3dPrint/shaft_OpenDecabotMINIV1.stl
70.0 x 4.80 x 4.80

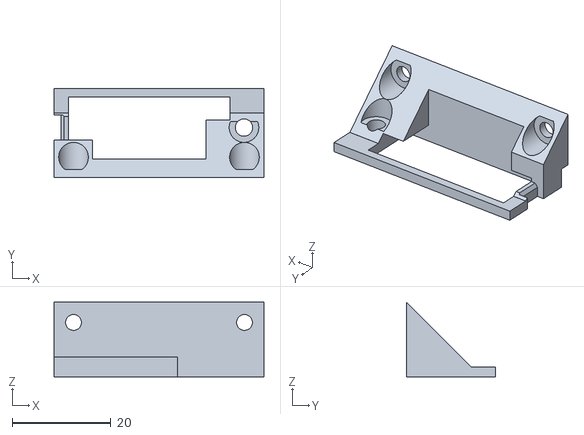
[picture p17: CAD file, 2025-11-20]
3dPrint/accessories/clawBase_OpenDecabotMINIV1.stl
42.5 x 18.0 x 15.1

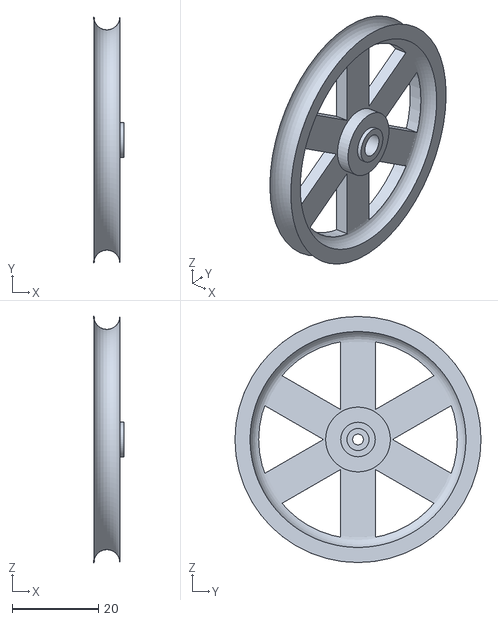
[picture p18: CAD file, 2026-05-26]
3dPrint/wheel_OpenDecabotMINIV1.stl
7.00 x 57.0 x 57.0

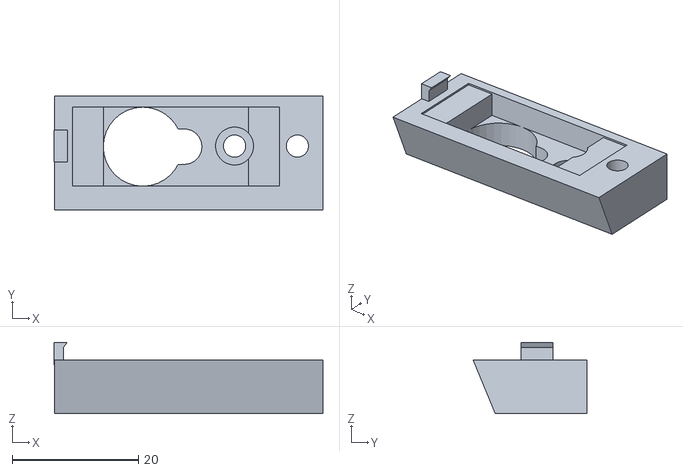
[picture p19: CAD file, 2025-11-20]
3dPrint/accessories/clawTop_OpenDecabotMINIV1.stl
42.6 x 18.0 x 11.3

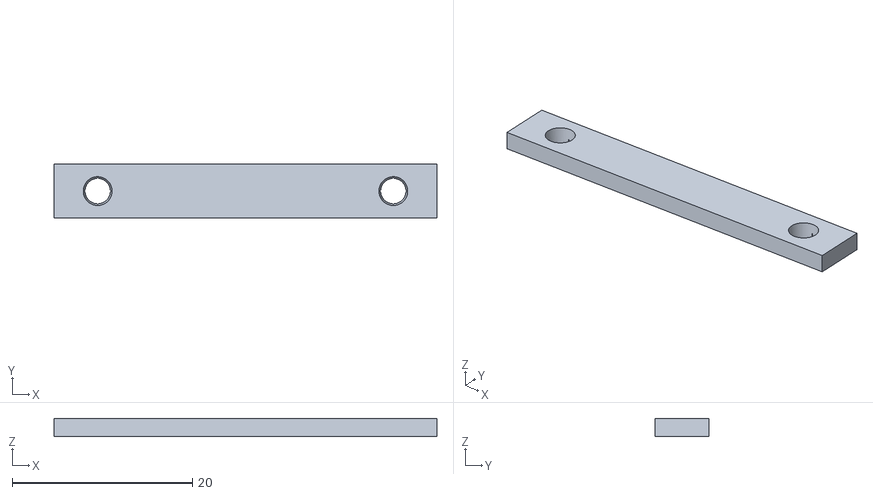
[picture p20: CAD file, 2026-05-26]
3dPrint/boardguide_OpenDecabotMINIV1.stl
42.5 x 6.00 x 2.00

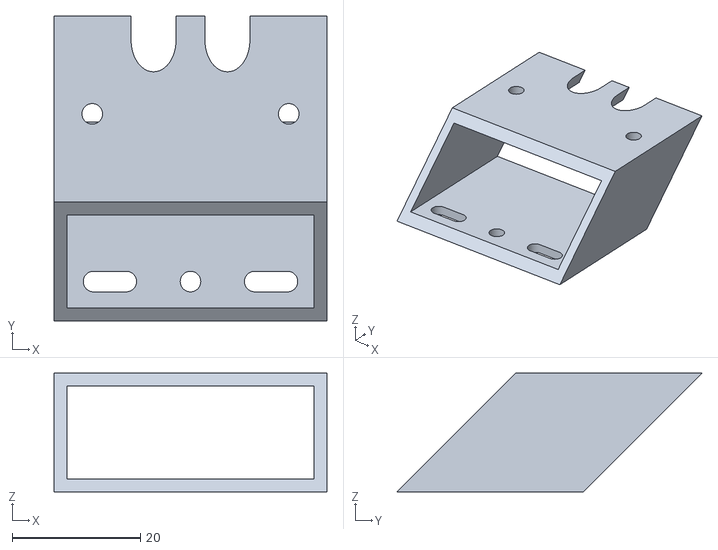
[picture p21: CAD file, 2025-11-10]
3dPrint/accessories/lineFollow_OpenDecabotMINIV1.stl
42.5 x 47.5 x 18.5

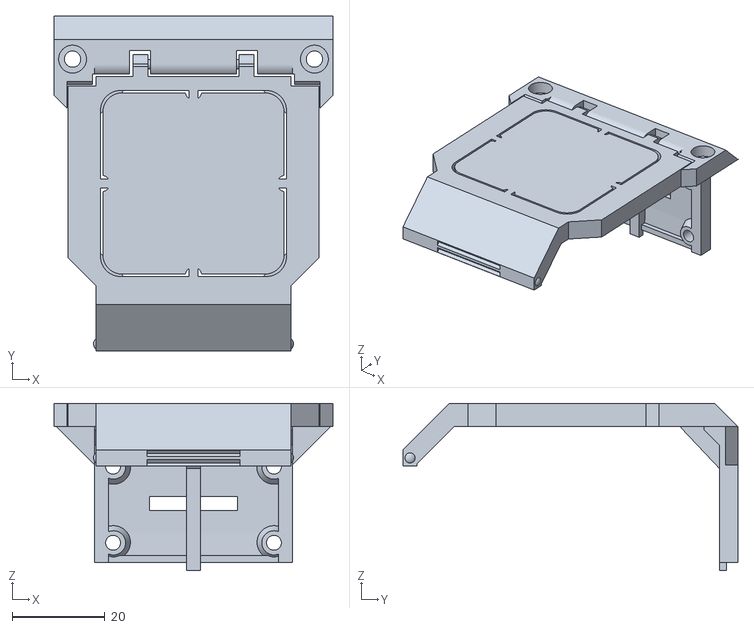
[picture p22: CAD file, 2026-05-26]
3dPrint/top_OpenDecabotMINIV1.stl
60.0 x 72.0 x 36.0

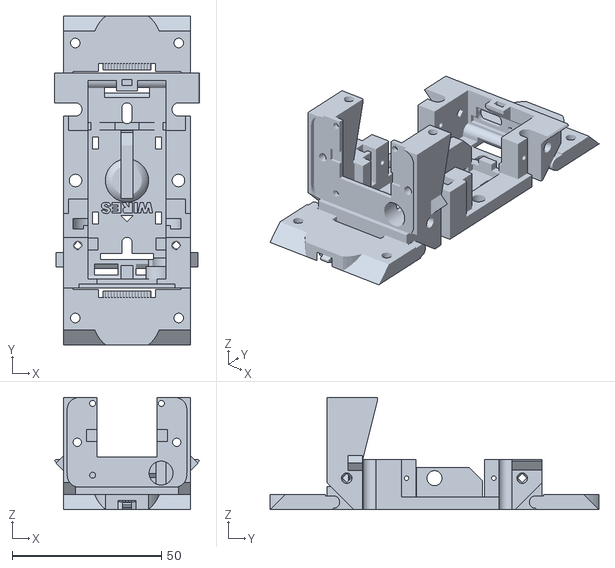
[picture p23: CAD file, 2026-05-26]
3dPrint/bottom_OpenDecabotMINIV1.stl
48.5 x 110.0 x 37.5

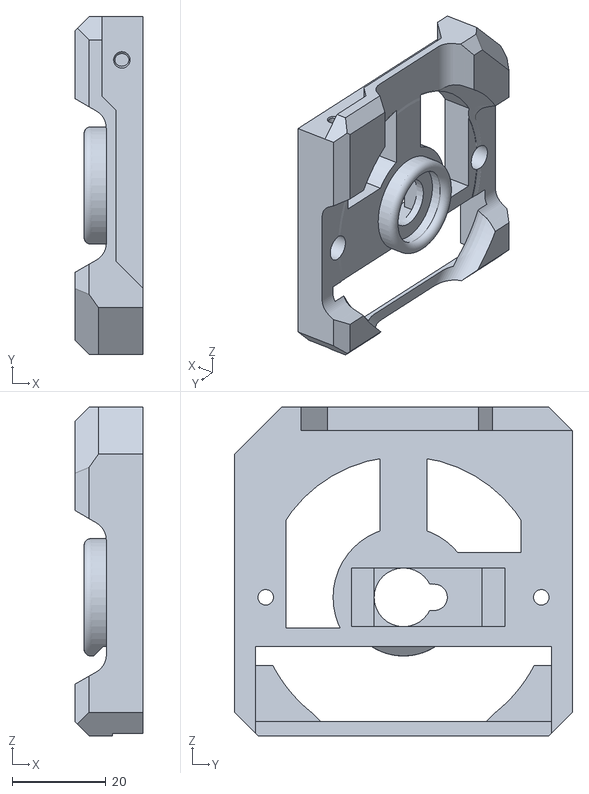
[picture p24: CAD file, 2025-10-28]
3dPrint/right_OpenDecabotMINIV1.stl
14.5 x 72.0 x 70.0

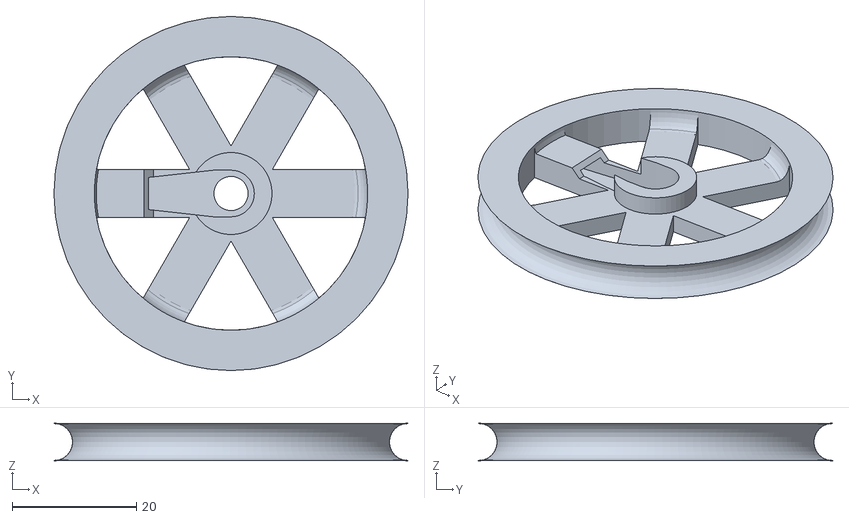
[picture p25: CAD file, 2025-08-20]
3dPrint/wheelWithSupport_OpenDecabotMINIV1.stl
57.0 x 57.0 x 6.00

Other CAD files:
3dPrint/left_OpenDecabotMINIV1.stl

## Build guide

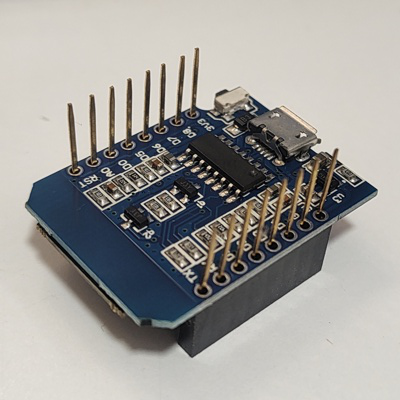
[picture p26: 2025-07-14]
images/componentsWemos_wemosD1MiniAssembled.JPG

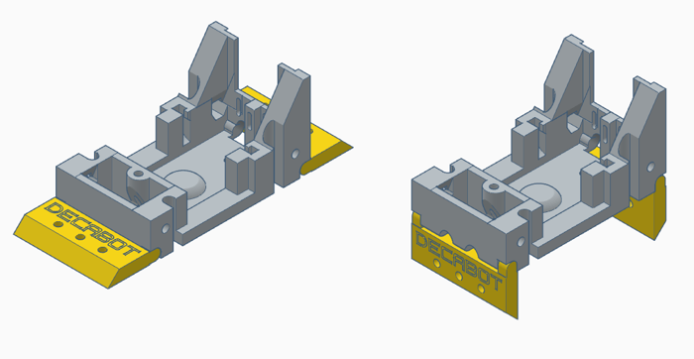
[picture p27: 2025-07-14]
images/montagemOpenDecabot_0.png

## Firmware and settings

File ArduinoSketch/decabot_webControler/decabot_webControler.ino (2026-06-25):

/*
 * Captive Portal Decabot
 * Daniel Chagas, Nicole Akemi Takeda, Cauan Oliveira, Paulo Roberto Gomes
 *
 * Robô cria uma rede wifi com captive portal que exibe botões de controle
 * remoto que controlam os servo motores ligados às portas D0 (motor direito)
 * e D6 (motor esquerdo). 
 *
 * To use:
 * - Access the Wi-Fi network 'MeuDecabot' with a device such as smartphone,
 *   tablet or computer, and click on the login message. 
 * - You must see a page with a title and buttons who can control the movement
 * 
 * Hardware:
 * Wemos D1 Mini - https://www.wemos.cc/en/latest/d1/index.html
 * Matrix Led Shield - https://github.com/wemos/WEMOS_Matrix_LED_Shield_Arduino_Library
 * Decabot Mini Shield
 * 
 * PORTS                             _____________
 *                                  /             \
 *                             RST |*  ---------  *| TX 
 *           battery ---------- A0 |* |         | *| RX
 *         SERVO esq --GPIO16-- D0 |* |  ESP    | *| D1 ---I2C--- SCL
 *    led matrix CLK ---------- D5 |* |  8266   | *| D2 ---I2C--- SDA
 *         SERVO dir --GPIO12 - D6 |* |         | *| D3 --GPIO0-- SERVO
 *    led matrix DIN ---------- D7 |* |         | *| D4 --GPIO2
 *            buzzer --GPIO15-- D8 |*  ---------  *| GND
 *                             3V3 |*             *| 5V
 *                                  \              |
 *                            reset  |      D1mini |
 *                                    \___________/
 */


#include <ESP8266WiFi.h>
#include <ESPAsyncTCP.h>        //tested on 1.2.4 from dvarrel https://github.com/dvarrel/ESPAsyncTCP
#include <ESPAsyncWebServer.h>  //tested on 3.1.0 from lacamera https://github.com/lacamera/ESPAsyncWebServer
#include <DNSServer.h>
#include <Servo.h>
#include <Adafruit_GFX.h>       // tested on 1.11.10 by Adafruit
#include <WEMOS_Matrix_GFX.h>   // tested on 1.4.0 from Thomas O Fredericks https://github.com/thomasfredericks/wemos_matrix_gfx 
#include <ArduinoUniqueID.h>    // tested on 1.3.0 from Cassettari https://github.com/ricaun/ArduinoUniqueID 
#define buzzer D8
#define battery A0
#include "index_html.h"
const String version = "1.0.20260625";
const char compile_date[] = __DATE__ " " __TIME__;

/* SETUP DECABOT - Change here parameters! Mude aqui parâmetros do seu robô! */
String setupRobotName = "";
String ssid = "MeuDecabot";
const char *password = "";
bool showBattery = false; //if the robot has battery measurement circuit

MLED matrix(7); // intensidade 7 (máximo)
int lpos = 1; // posição olho esquerdo
int rpos = 6; // posição olho direito
int aleat = 5;
bool awake = false;
uint8_t contDisplayWifi = 0;

//motors
Servo motorDir;
Servo motorEsq;
char caractere = ' ';
String txtSerial = "";
int velocidade = 0; //velocidade geral do robô
int direcao = 0;
long timerDist = 0;
//variáveis de calibração
int motorEsqMin = 33; //calibra com 'a'
int motorEsqZero = 93; //calibra com 'b'
int motorEsqMax = 153; //calibra com 'c'
int motorDirMin = 153; //calibra com 'q'
int motorDirZero = 93; //calibra com 'r'
int motorDirMax = 33; //calibra com 's'

//battery vars
int batValue = 0;
const float minBat = 3.2;
bool charging = false;
int chargingImageStep = 0;
long batTimer = 0;
bool showingBat = false;
bool batteryAllarm = false;

static const uint8_t PROGMEM wifiLogo[] = {B01111110,B10000001,B00111100,B01000010,B00011000,B00100100,B00011000,B00011000};

static const uint8_t PROGMEM miniNumbers[10][5] = {{0x2, 0x5, 0x5, 0x5, 0x2},{0x2, 0x6, 0x2, 0x2, 0x7},{0x6, 0x1, 0x2, 0x4, 0x7},{0x6, 0x1, 0x2, 0x1, 0x6},{0x1, 0x5, 0x7, 0x1, 0x1},{0x7, 0x4, 0x6, 0x1, 0x6},{0x3, 0x4, 0x6, 0x5, 0x2},{0x7, 0x1, 0x2, 0x2, 0x2},{0x2, 0x5, 0x2, 0x5, 0x2},{0x2, 0x5, 0x3, 0x1, 0x6}};

//sounds
const int decabotMusic[4][3]{ { 494, 2, 3 }, { 554, 2, 4 }, { 440, 2, 5 }, { 880, 1, 6 } };
static const uint8_t PROGMEM decabotLogo[4][5] = {{0b11001110,0b10101000,0b10101100,0b10101000,0b11001110},{0b00110010,0b01000101,0b01000111,0b01000101,0b00110101},{0b11000100,0b10101010,0b11001010,0b10101010,0b11000100},{0b01110100,0b00100100,0b00100100,0b00100000,0b00100100}};

DNSServer dnsServer;
const byte DNS_PORT = 53;

AsyncWebServer server(80);

const int LED_PIN = LED_BUILTIN;
bool ledState = false;

void setup() {
  Serial.begin(115200);
  Serial.println();
  Serial.println();
  Serial.println("Copyright (C) Decano Robotics - www.decabot.com");
  Serial.print("Decabot Version: ");
  Serial.print(version);
  Serial.print(" - ");
  Serial.println(compile_date);
  Serial.println("MAC: " + WiFi.macAddress());
  Serial.println("Robot ID " + decabotUniqueID());
  setupRobotName = decabotName(decabotUniqueID());
  ssid = "decabot_" + setupRobotName;
  pinMode(buzzer, OUTPUT);
  matrix.setRotation(2);
  matrix.setTextSize(1);
  matrix.setTextWrap(false);
  matrix.setTextColor(LED_ON);
  motorDir.attach(D0, 500, 2400); //setup for correct PWM on ESP8266
  motorEsq.attach(D6, 500, 2400); //setup for correct PWM on ESP8266
  pinMode(LED_PIN, OUTPUT);
  digitalWrite(LED_PIN, HIGH); // LED off (ativo em LOW)
  ledState = false;

  WiFi.mode(WIFI_AP);
  WiFi.softAP(ssid, password);
  IPAddress myIP = WiFi.softAPIP();
  Serial.print("AP IP address: ");
  Serial.println(myIP);

  dnsServer.start(DNS_PORT, "*", myIP);

  // Página raiz (cativa)
  server.on("/", HTTP_GET, [myIP](AsyncWebServerRequest *request) {
    awake = true;
    String ipStr = myIP.toString();
    

    request->send(200, "text/html", html);
  });

  // Comandos: Front / Left / Right / Back / Stop
  server.on("/led", HTTP_GET, [](AsyncWebServerRequest *request) {
    if (request->hasParam("state")) {
      String state = request->getParam("state")->value();

      if (state == "Front") {
        frente(100);
      } else if (state == "Left") {
        esquerda(100);
      } else if (state == "Right") {
        direita(100);
      } else if (state == "Back") {
        tras(50);
      } else if (state == "Stop") {
        pare();
      } else {
        request->send(400, "text/plain", "Invalid state");
        return;
      }

      request->send(200, "text/plain", ledState ? "ON" : "OFF");
    } else {
      request->send(400, "text/plain", "Missing parameter");
    }
  });

  server.on("/status", HTTP_GET, [](AsyncWebServerRequest *request) {
    request->send(200, "text/plain", ledState ? "ON" : "OFF");
  });

  server.onNotFound(notFound);
  server.begin();
  for (int i = 0; i < 4; i++) {
    matrix.clear();
    matrix.drawBitmap(0, 2, decabotLogo[i] , 8, 5, LED_ON);
    matrix.writeDisplay();
    tone(buzzer, decabotMusic[i][0], decabotMusic[i][1] * 200);
    delay(decabotMusic[i][1] * 200);
    noTone(buzzer);
  }
  delay(500);
  matrix.clear();
  Serial.print("I am an openDecabot and my name is ");
  Serial.println(setupRobotName);
}

void loop() {
  dnsServer.processNextRequest();
  if(Serial.available()>0){
    caractere = Serial.read();
    if(caractere == '\n'){
    	maquinaDeEstados(txtSerial);
        txtSerial = "";
    } else {
     	txtSerial = txtSerial + caractere;
    }
  }
  if(millis()>batTimer){
    if(showingBat){
      batTimer = millis() + 100;
      showingBat = false;
      if(awake){
        // animação dos olhos + buzzer (mantida)
        matrix.clear();
        matrix.drawLine(lpos, 2, lpos, 7, LED_ON);
        matrix.drawLine(rpos, 2, rpos, 7, LED_ON);
        matrix.writeDisplay();
        delay(1000);

        // efeito de piscar
        for (int j = 0; j < random(3); j++) {
          for (int i = 2; i < 7; i++) {
            matrix.clear();
            matrix.drawLine(lpos, i, lpos, 7, LED_ON);
            matrix.drawLine(rpos, i, rpos, 7, LED_ON);
            matrix.writeDisplay();
            digitalWrite(buzzer, HIGH);
            delay(15);
            digitalWrite(buzzer, LOW);
            delay(15);
          }
          for (int i = 7; i > 2; i--) {
            matrix.clear();
            matrix.drawLine(lpos, i, lpos, 7, LED_ON);
            matrix.drawLine(rpos, i, rpos, 7, LED_ON);
            matrix.writeDisplay();
            digitalWrite(buzzer, HIGH);
            delay(15);
            digitalWrite(buzzer, LOW);
            delay(15);
          }
        }
      
        // olhar para os lados
        aleat = random(10);
        if (aleat < 2) {
          lpos = 0;
          rpos = 5;
        } else if (aleat > 7) {
          lpos = 2;
          rpos = 7;
          delay(15);
        } else {
          lpos = 1;
          rpos = 6;
          delay(15);
        }
      } else {
        decabotShowName();
        delay(100);
      }
    } else {
      if(showBattery) {
        decabotShowBatLevel();
        batTimer = millis() + 1000;
      }
      showingBat = true;
    }
  }
}

void notFound(AsyncWebServerRequest *request) {
  request->redirect("/");
}

void maquinaDeEstados(String txtDigitado){
  //função que recebe o texto e separa o comando do parâmetro
  String comando = txtDigitado.substring(0,1);
  String parametro = txtDigitado.substring(1,txtDigitado.length());
  Serial.println("Comando " + comando + " e Parametro " + parametro);
  //agora vamos fazer os comandos atuarem no robô!
  switch(comando.charAt(0)){
    case 'a':
    	Serial.println("Calibrando motor Esq Min");
    	motorEsqMin = parametro.toInt();
    	break;
    case 'b':
    	Serial.println("Calibrando motor Esq Zero");
    	motorEsqZero = parametro.toInt();
    	break;
    case 'c':
    	Serial.println("Calibrando motor Esq Max");
    	motorEsqMax = parametro.toInt();
    	break;
    case 'q':
    	Serial.println("Calibrando motor Dir Min");
    	motorDirMin = parametro.toInt();
    	break;
    case 'r':
    	Serial.println("Calibrando motor Dir Zero");
    	motorDirZero = parametro.toInt();
    	break;
    case 's':
    	Serial.println("Calibrando motor Dir Max");
    	motorDirMax = parametro.toInt();
    	break;
    case 'y':
    	//recebe o parametro Y do joystick (cima e baixo)
    	velocidade = parametro.toInt();
    	break;
    case 'x':
    	//recebe o parametro X do joystick (esquerda e direita)
    	direcao = parametro.toInt();
    	moveDir(velocidade - (direcao/2));
    	moveEsq(velocidade + (direcao/2));
    	Serial.println("Virando a " + (String)direcao + " na velocidade" + (String)velocidade);
    	break;
    case 'f':
    	frente(parametro.toInt());
    	break;
    case 't':
    	tras(parametro.toInt());
    	break;
    case 'd':
    	direita(parametro.toInt());
    	break;
    case 'e':
    	esquerda(parametro.toInt());
    	break;
    case 'p':
    	pare();
    	break;
    case '?':
      Serial.print("Decabot ");
      Serial.println(ssid);
      break;
    default:
    	Serial.println("Comando desconhecido!");
  }  
}

void frente(int potencia){
  moveDir(potencia);
  moveEsq(potencia);
  Serial.println("Andando para frente na potencia " + (String)potencia);
}

void tras(int potencia){
  moveDir(-potencia);
  moveEsq(-potencia);
  Serial.println("Andando para tras na potencia " + (String)potencia);
}

void direita(int potencia){
  moveDir(-potencia);
  moveEsq(potencia);
  Serial.println("Virando para direita na potencia " + (String)potencia);
}

void esquerda(int potencia){
  moveDir(potencia);
  moveEsq(-potencia);
  Serial.println("Virando para esquerda na potencia " + (String)potencia);
}

void pare(){
  moveDir(0);
  moveEsq(0);
  Serial.println("Parada!");
}

void moveDir(int potencia){
  int saida = 0;
  if(potencia>=0){
  	saida = map(potencia,0,100,motorDirZero,motorDirMax);
  } else {
    saida = map(potencia,-100,0,motorDirMin,motorDirZero);
  }
  motorDir.write(saida);
}

void moveEsq(int potencia){
  int saida = 0;
  if(potencia>=0){
  	saida = map(potencia,0,100,motorEsqZero,motorEsqMax);
  } else {
    saida = map(potencia,-100,0,motorEsqMin,motorEsqZero);
  }
  motorEsq.write(saida);
}

int readBatteryLevel(){
  int reading = map(analogRead(battery),704,955,0,100);
  if (reading<0) reading = 0;
  if (reading>100) reading = 100;
  if (reading<10){
    if(batteryAllarm){
      batteryAllarm = false;
      noTone(buzzer);
    } else {
      batteryAllarm = true;
      tone(buzzer, 494, 200);
    }
  }
  if(reading==100){
    charging = true;
  } else {
    charging = false;
  }
  return reading;
}

void decabotShowBatLevel(){
  matrix.clear();
  matrix.drawRect(0,2, 7,4, LED_ON);
  matrix.drawLine(7,3,7,4, LED_ON);
  if(charging){
    matrix.fillRect(1,3, chargingImageStep,2, LED_ON);
    chargingImageStep++;
    if(chargingImageStep>5) chargingImageStep = 0;
    matrix.writeDisplay();
    delay(200);
  } else {
    matrix.fillRect(1,3, map(readBatteryLevel(),0,100,0,5),2, LED_ON);
    matrix.writeDisplay();
  }
}

void showMiniNumbers(int value){
  int tens = value/10;
  int units = value - tens*10;
  matrix.clear();
  matrix.drawBitmap(0, 1, miniNumbers[units] , 8, 5, LED_ON);
  matrix.drawBitmap(-4, 1, miniNumbers[tens] , 8, 5, LED_ON);
  matrix.writeDisplay();
}

String decabotUniqueID(){
  String id = "";
  for (size_t i = 0; i < UniqueIDsize; i++){
    if (UniqueID[i] < 0x10) id = id + "0";
    id = id + UniqueID[i];
  }
  return id;
}

String decabotName(String entrada) {
  uint16_t hashCalculado = 0;

  for (unsigned int i = 0; i < entrada.length(); i++) {
    hashCalculado += entrada.charAt(i);
    hashCalculado += (hashCalculado << 10);
    hashCalculado ^= (hashCalculado >> 6);
  }
  hashCalculado += (hashCalculado << 3);
  hashCalculado ^= (hashCalculado >> 11);
  hashCalculado += (hashCalculado << 15);

  const char caracteres[] = "ABCDEFGHIJKLMNOPQRSTUVWXYZ0123456789";
  String hashResultado = "";

  for (int i = 0; i < 4; i++) {
    uint16_t indice = (hashCalculado + (i * 17)) % 36; 
    hashResultado += caracteres[indice];
    hashCalculado >>= 4; 
  }

  return hashResultado;
}

void decabotShowName(){
  if(contDisplayWifi<20){
    matrix.drawBitmap(0, 0, wifiLogo , 8, 8, LED_ON);
  } else {
    matrix.clear();
    matrix.setCursor((contDisplayWifi - 20) * -1,1);
    matrix.print("  " + setupRobotName + " ");
  }
  matrix.writeDisplay();
  contDisplayWifi++;
  if(contDisplayWifi>56) contDisplayWifi=0;
}

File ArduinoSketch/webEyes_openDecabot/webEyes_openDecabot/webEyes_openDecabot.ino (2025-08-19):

/*
 * Captive Portal Decabot
 * Daniel Chagas
 * 
 * Creates a Captive Portal webpage with simple comands. 
 * 
 * To use:
 * - Access the Wi-Fi network 'MeuDecabot' with a device such as smartphone,
 *   tablet or computer, and click on the login message. 
 * - You must see a page with a title and two buttons who can control the 
 *   blue LED inside your Decabot (must be visible from the top or from
 *   the frontal holes. 
 * - Click on the buttons to change it's state.
 * 
 * Hardware:
 * Wemos D1 Mini - https://www.wemos.cc/en/latest/d1/index.html
 * Matrix Led Shield - https://github.com/wemos/WEMOS_Matrix_LED_Shield_Arduino_Library
 * Decabot Mini Shield
 * 
 * PORTS                             _____________
 *                                  /             \
 *                             RST |*  ---------  *| TX 
 *           battery ---------- A0 |* |         | *| RX
 *         SERVO esq --GPIO16-- D0 |* |  ESP    | *| D1 ---I2C--- SCL
 *    led matrix CLK ---------- D5 |* |  8266   | *| D2 ---I2C--- SDA
 *         SERVO dir --GPIO12 - D6 |* |         | *| D3 --GPIO0-- SERVO
 *    led matrix DIN ---------- D7 |* |         | *| D4 --GPIO2
 *            buzzer --GPIO15-- D8 |*  ---------  *| GND
 *                             3V3 |*             *| 5V
 *                                  \              |
 *                            reset  |      D1mini |
 *                                    \___________/
 */

#include <Adafruit_GFX.h>       //tested on version 1.11.10
#include <WEMOS_Matrix_GFX.h>   //tested on version 1.4.0
#include <ESP8266WiFi.h>
#include <ESPAsyncTCP.h>
#include <ESPAsyncWebServer.h>
#include <DNSServer.h>
#include <ArduinoUniqueID.h>

const char *ssid = "MeuDecabot";
const char *password = "";

MLED matrix(7); //set intensity=7 (maximum)

//emotion variables
int eyeTypeVar = 4; //select between 0 to 4
int eyePosLR = 0; //-1, 0 or 1
int eyePosUD = 0; //-1, 0 or 1
int eyeBrowPosUD = -2; //0 close to 5 full open
int eyeBrowEmotion = 0; //-1, 0 or 1
int matrixUpdate = 0;
int blinkTimer = 2000;
int blinkState = 0;
int lastCommandTimmer = 0;

int temp = 0;
int positionLoadLine = 0;

//sounds
const int decabotMusic[4][3]{{494,2,3},{554,2,4},{440,2,5},{880,1,6}};

//bitmaps
static const uint8_t PROGMEM eyes_bmp[7][8] = {
  {B00000000,B00000000,B10100101,B01000010,B10100101,B00000000,B00000000,B00000000},  //dead
  {B00000000,B00000000,B00001000,B00011000,B00001000,B00001000,B00011100,B00000000},  //1 battery levels
  {B00000000,B00000000,B00111000,B00000100,B00011000,B00100000,B00111100,B00000000},  //2
  {B00000000,B00000000,B00111000,B00000100,B00011000,B00000100,B00111000,B00000000},  //3
  {B00000000,B00000000,B00010100,B00100100,B00111100,B00000100,B00000100,B00000000},  //4
  {B00000000,B00000000,B00111100,B00100000,B00111000,B00000100,B00111000,B00000000},  //5
  {B01010000,B01010000,B11111000,B11111000,B01110000,B00100000,B00010000,B00001111}   // charging
};

static const uint8_t PROGMEM numbers[20][8] = {
  {0b00111100,0b01111110,0b01100110,0b01100110,0b01100110,0b01100110,0b01111110,0b00111100}, //0
  {0b00011000,0b00111000,0b01111000,0b00011000,0b00011000,0b00011000,0b01111110,0b01111110}, //1
  {0b00111100,0b01111110,0b01100110,0b00001110,0b00011100,0b00111000,0b01111110,0b01111110}, //2
  {0b01111100,0b01111110,0b00000110,0b00011110,0b00011110,0b00000110,0b01111110,0b01111100}, //3
  {0b00011110,0b00111110,0b00110110,0b01100110,0b01111110,0b01111110,0b00000110,0b00000110}, //4
  {0b01111110,0b01111110,0b01100000,0b01111100,0b01111110,0b00000110,0b01111110,0b01111100}, //5
  {0b00111100,0b01111100,0b01100000,0b01111100,0b01111110,0b01100110,0b01111110,0b00111100}, //6
  {0b01111110,0b01111110,0b00000110,0b00001110,0b00011100,0b00011000,0b00011000,0b00011000}, //7
  {0b00111100,0b01111110,0b01100110,0b00111100,0b01111110,0b01100110,0b01111110,0b00111100}, //8
  {0b00111100,0b01111110,0b01100110,0b01111110,0b00111110,0b00000110,0b00111110,0b00111100}, //9
  {0b11001110,0b11011111,0b11011011,0b11011011,0b11011011,0b11011011,0b11011111,0b11001110}, //10
  {0b01100011,0b11100111,0b11100111,0b01100011,0b01100011,0b01100011,0b01100011,0b01100011}, //11
  {0b11011110,0b11011111,0b11000011,0b11000111,0b11001100,0b11011000,0b11011111,0b11011111}, //12
  {0b11011110,0b11011111,0b11000011,0b11001111,0b11001111,0b11000011,0b11011111,0b11011110}, //13
  {0b11000111,0b11001111,0b11011111,0b11011011,0b11011111,0b11011111,0b11000011,0b11000011}, //14
  {0b11011111,0b11011111,0b11011000,0b11011110,0b11011111,0b11000011,0b11011111,0b11011110}, //15
  {0b11001110,0b11011110,0b11011000,0b11011110,0b11011111,0b11011011,0b11011111,0b11001110}, //16
  {0b11011111,0b11011111,0b11000011,0b11000111,0b11001110,0b11001100,0b11001100,0b11001100}, //17
  {0b11001110,0b11011111,0b11011011,0b11001110,0b11011111,0b11011011,0b11011111,0b11001110}, //18
  {0b11001110,0b11011111,0b11011011,0b11011111,0b11001111,0b11000011,0b11001111,0b11001110}  //19
};

DNSServer dnsServer;
const byte DNS_PORT = 53;

AsyncWebServer server(80);

const int LED_PIN = LED_BUILTIN;
bool ledState = false;

void notFound(AsyncWebServerRequest *request) {
  request->redirect("/");
}
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

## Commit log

2025-07-03 first commit
    Included 3D files, PCB files and some images.
    [bottom_OpenDecabotMINIV1.stl, left_OpenDecabotMINIV1.stl, lineFollow_OpenDecabotMINIV1.stl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]
2025-07-05 updated PCB images
2025-07-09 Update webSimple_openDecabot.ino
    With buttons
2025-07-13 Created assembling images
2025-08-19 update on 3D files and images
    [bottom_OpenDecabotMINIV1.stl]
2025-08-20 Update on 3D files
    Better quality when using simple 3D printers.
    [top_OpenDecabotMINIV1.stl, wheelWithSupport_OpenDecabotMINIV1.stl]
2025-08-20 Better 3D model
    [wheelWithSupport_OpenDecabotMINIV1.stl]
2025-08-21 New likert images
    [top_OpenDecabotMINIV1.stl]
2025-08-27 New 3D version files
    [boardguide_OpenDecabotMINIV1.stl, bottom_OpenDecabotMINIV1.stl, left_OpenDecabotMINIV1.stl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]
2025-09-05 improvement on screw holes
    [left_OpenDecabotMINIV1.stl, right_OpenDecabotMINIV1.stl]
2025-11-10 Update bottom_OpenDecabotMINIV1.stl
    Now compatible with 18650 battery.
    [bottom_OpenDecabotMINIV1.stl]
2025-11-20 Update bottom_OpenDecabotMINIV1.stl
    Better connection with top part, included in fille support, new position of accessories holes.
    [bottom_OpenDecabotMINIV1.stl]
2025-11-20 Included 3D claw accessories
    [clawBase_OpenDecabotMINIV1.stl, clawTop_OpenDecabotMINIV1.stl, claw_OpenDecabotMINIV1.stl]
2026-05-08 Implement wake/sleep button functionality
    Added buttons for waking and sleeping states with visibility control.
2026-05-14 radical changes to improve code
    Included state machine function, changed motor codes and calibration, included serial functions and debug, included optional battery measurement.
2026-05-17 Refactor and update Decabot web controller code
    Adicionei um painel de Debug na página web q recebe as ações do robô e uma função de sleep/awake
2026-05-20 Revert "Urgent update to correct servo control"
    This reverts commit 45668a50ac40b80c1e2522aeea92cef37f40fd60.
    [decabot_webControler.ino]
2026-05-20 correct PWM command
2026-05-21 Updated 3D parts
    Improvement on assembling, included charger on bottom chassis, fixed wheel file.
    [boardguide_OpenDecabotMINIV1.stl, bottom_OpenDecabotMINIV1.stl, top_OpenDecabotMINIV1.stl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]
2026-06-29 Criando estrutura de aulas
    Aula blink criada.
2026-06-29 Aulas de funções e mapeamento
